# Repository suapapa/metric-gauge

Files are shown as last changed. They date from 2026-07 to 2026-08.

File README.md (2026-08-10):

# Metric Gauge

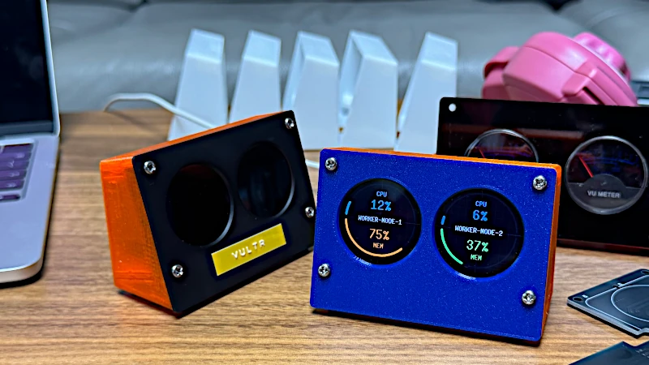
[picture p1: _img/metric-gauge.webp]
metric-gauge


ESP32-C3 Super Mini + dual **GC9A01** round LCDs (240×240). Each display shows a circle gauge with **CPU** and **MEM** from a Prometheus metrics URL (node-exporter or mon64 export).

Metric source sibling project: [mon64](https://github.com/suapapa/mon64).

## Hardware

| Part | Notes |
|---|---|
| MCU | ESP32-C3 Super Mini |
| Displays | 2× GC9A01 1.28″ round TFT, **4-wire SPI** |

> GC9A01 modules often label MOSI/SCK as **SDA/SCL**. That is still SPI, not I²C.

### Pin map

| Signal | GPIO | Notes |
|---|---|---|
| SCK (SCL) | **6** | Shared SPI clock |
| MOSI (SDA) | **7** | Shared SPI data |
| RST | **0** | Shared reset |
| BL | **5** | Shared backlight (driven high) |
| CS1 | **10** | Gauge 1 chip select |
| DC1 | **1** | Gauge 1 data/command |
| CS2 | **3** | Gauge 2 chip select |
| DC2 | **4** | Gauge 2 data/command |

Avoid strapping pins **2 / 8 / 9** for CS/DC if possible. UART0 (**20/21**) is left free for USB serial.

Power both modules from **3V3** (logic is 3.3 V). Do not feed 5 V into GPIO.

## Build / flash

Requires a Rust nightly toolchain with `riscv32imc-unknown-none-elf` (see `rust-toolchain.toml`) and [`espflash`](https://github.com/esp-rs/espflash).

Compile-time env vars (required for a useful image):

| Env | Alias | Purpose |
|-----|---|---|
| `SSID` | — | Wi-Fi SSID |
| `PASS` | `PASSWORD` | Wi-Fi password |
| `GAUGE1_PROM_METRIC` | — | Prometheus URL for display 1 |
| `GAUGE2_PROM_METRIC` | — | Prometheus URL for display 2 |
| `GAUGE1_ROTATION` | — | Rotation for display 1 (`0`, `90`, `180`, `270` or `RotateX`) |
| `GAUGE2_ROTATION` | — | Rotation for display 2 (`0`, `90`, `180`, `270` or `RotateX`) |
| `GAUGE1_NAME` | — | Name of the gauge 1 (drawn on the display 1) |
| `GAUGE2_NAME` | — | Name of the gauge 2 (drawn on the display 2) |

Copy `.env.sample` to `.env` and edit it to fit your configuration:

```bash
cp .env.sample .env
# Edit the .env file to set your SSID, PASS, and metrics endpoints
```

Run and flash directly (uses the runner in `.cargo/config.toml` to call `espflash flash --monitor --chip esp32c3`):

```bash
cargo run --release
```

Build only:

```bash
cargo build --release
```

Flash an already-built binary:

```bash
espflash flash --monitor --chip esp32c3 \
  target/riscv32imc-unknown-none-elf/release/metric-gauge
```

### Metrics notes

- Scrapes every **10 s** over HTTPS (TLS cert verification disabled). Each gauge keeps its TCP/TLS connection alive between scrapes when the server allows HTTP/1.1 keep-alive.
- Supports **node-exporter** (`node_cpu_seconds_total`, `node_memory_MemTotal_bytes` / `MemAvailable_bytes`) and **mon64** gauges (`mon64_node_cpu_percent`, `mon64_node_mem_used_percent`, …).
- Node-exporter CPU needs two samples: first scrape shows `n/a` for CPU, then deltas work.
- Hostname label on the gauge is configured via `GAUGE1_NAME` and `GAUGE2_NAME` (e.g. `node1`, `node2`).
- Displays share one static 240×240 RGB565 framebuffer (~112 KiB); both LCDs are painted sequentially over the shared SPI bus.

## License

This project is licensed under the MIT License - see the [LICENSE](LICENSE) file for details.

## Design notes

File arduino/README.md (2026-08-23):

# Metric Gauge (Arduino)

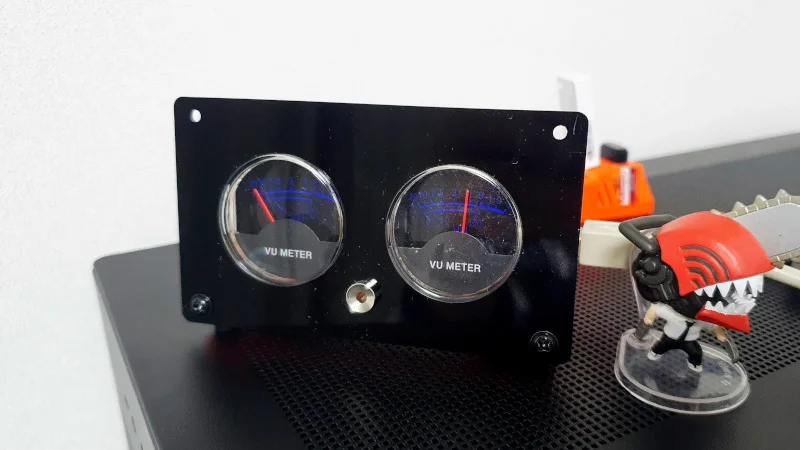
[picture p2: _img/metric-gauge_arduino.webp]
metric_gauge


Analog dual-gauge display driven by an Arduino over USB serial. A small Go daemon on the host reads CPU and memory usage (locally via gopsutil, or from a node-exporter `/metrics` URL) and sends PWM targets to the board.

For the ESP32-C3 + GC9A01 digital gauge firmware, see the [project README](../README.md).

## Hardware

| Part | Notes |
|---|---|
| MCU | Arduino (or compatible board with `analogWrite`) |
| Gauges | 2× analog meter movements on PWM outputs |
| Host link | USB serial, **9600** baud |

### Pin map (`dual_gauge.ino`)

| Signal | Pin | Notes |
|---|-----|---|
| Gauge 1 (A1) | **11** | PWM output |
| Gauge 2 (A2) | **10** | PWM output |
| Status LED | `LED_BUILTIN` | Blinks while a serial command is processed |

Values are mapped from 0–100 (percent) to 0–255 (PWM). The sketch ramps the needle smoothly (~10 ms per step) instead of jumping instantly.

## Flash the Arduino sketch

1. Open [`dual_gauge.ino`](dual_gauge.ino) in the Arduino IDE.
2. Select your board and serial port.
3. Upload.

On boot the sketch prints:

```
Type command: A=[0-100],[0-100] or A[1|2]=[0-100]
```

## Serial protocol

Commands are newline-terminated (`\n` or `\r\n`).

| Command | Effect |
|---|---|
| `A=<left>,<right>` | Set both gauges (each 0–100) |
| `A1=<value>` | Set gauge 1 only |
| `A2=<value>` | Set gauge 2 only |

Examples:

```
A=42,67
A1=80
A2=15
```

## Host daemon (`server/`)

The Go program opens the serial port and periodically writes `A=<cpu>,<mem>`.

### Run locally

```bash
cd server
go run . -s /dev/ttyUSB0 -i 15s
```

| Flag | Default | Purpose |
|---|---|---|
| `-s` | `/dev/ttyUSB0` | Serial device path |
| `-i` | `15s` | Scrape / update interval |
| `-nodeexporter` | *(empty)* | node-exporter `/metrics` URL; when set, local gopsutil is disabled |

**Local mode** (no `-nodeexporter`): reads CPU and memory from the machine running the daemon via [gopsutil](https://github.com/shirou/gopsutil).

**node-exporter mode**: fetches Prometheus text from the given URL. CPU usage is computed from `node_cpu_seconds_total` deltas (first sample may report 0% CPU until a second scrape). Memory is derived from `node_memory_MemTotal_bytes` and `node_memory_MemAvailable_bytes`.

On shutdown (SIGINT / SIGTERM) the daemon sends `A=0,0` to zero both gauges.

### Build & run with Docker

Build from the `server/` directory:

```bash
cd server
docker build -t dev/metric_gauge:latest .
```

Run with the serial device attached:

```bash
docker run \
  -d --restart unless-stopped \
  --device /dev/ttyUSB0 \
  --name metric_gauge \
  dev/metric_gauge:latest
```

Pass extra flags after the image name, for example:

```bash
docker run \
  -d --restart unless-stopped \
  --device /dev/ttyUSB0 \
  --name metric_gauge \
  dev/metric_gauge:latest \
  -i 10s -nodeexporter http://host.docker.internal:9100/metrics
```

Adjust `/dev/ttyUSB0` to match your adapter (`/dev/ttyACM0`, etc.).

## License

This project is licensed under the MIT License — see [LICENSE](../LICENSE).

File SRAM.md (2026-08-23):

빌드된 바이너리에서 SRAM 사용량을 집계해 표로 정리합니다.

현재 release 바이너리 기준입니다. (ESP32-C3 온칩 **SRAM 400 KiB**, 그중 ~16 KiB는 ICACHE)

## 칩 / 링커 창

| 구역 | 크기 |
|---|---|
| 온칩 SRAM 전체 | **400 KiB** |
| ICACHE | ~16 KiB |
| DRAM + dram2 창 | **~378 KiB** |
| IRAM용으로 예약(`.rwdata_dummy`와 동일 물리) | **~39 KiB** |

## 섹션별 (데이터 버스 DRAM)

| 섹션 | 크기 | 역할 |
|---|---|---|
| `.data` + `.data.wifi` | **~7.9 KiB** | 초기화 데이터 |
| `.bss` | **~197.6 KiB** | FB, HTTP 슬롯, Wi‑Fi BSS 등 |
| `.stack` | **~68.3 KiB** | 링커 스택 예약 |
| `.dram2_uninit` | **56.0 KiB** | `esp_alloc` heap (Wi‑Fi 동적 버퍼) |
| **합(더미 제외)** | **~330 KiB** | |

## `.bss` 안 큰 항목

| 항목 | 크기 |
|---|---|
| `FrameBuffer` 240×240 RGB565 | **~112.5 KiB** |
| HTTP keep-alive `SLOTS` ×2 (TCP+TLS 버퍼) | **~59.1 KiB** |
| embassy main task `POOL` | **~9.4 KiB** |
| Wi‑Fi `g_cnxMgr` 등 | **~수 KiB** |
| `StackResources` StaticCell | **~3.1 KiB** |

## IRAM (명령 버스, 같은 SRAM)

| 항목 | 크기 |
|---|---|
| `.rwtext.wifi` | **~33.0 KiB** |
| `.rwtext` + `.trap` | **~6.2 KiB** |
| **IRAM 합** | **~39 KiB** |

## 한눈에

| | |
|--|--|
| 앱이 크게 쓰는 곳 | FB **112** + HTTP×2 **59** + heap **56** + stack 예약 **68** |
| 여유 | dram2 heap 뒤 **~9 KiB**, 그 외는 거의 찬 편 |

물리적으로는 IRAM(~39)과 DRAM 데이터(~330)가 **같은 400 KiB SRAM**을 나눠 씁니다.

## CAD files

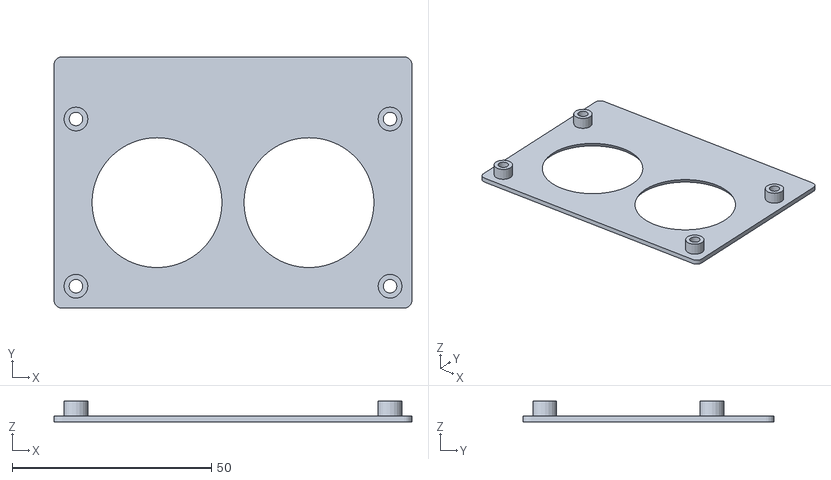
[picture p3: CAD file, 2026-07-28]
case/front.stl
89.7 x 63.0 x 5.20

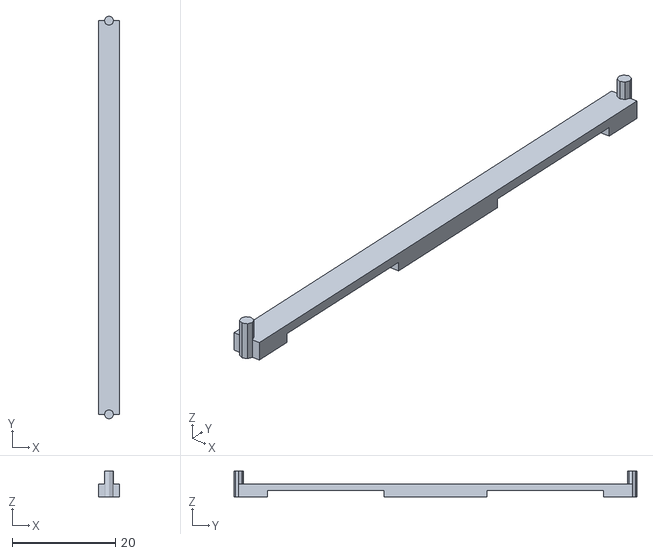
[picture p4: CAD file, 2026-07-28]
case/support.stl
4.00 x 78.0 x 5.00

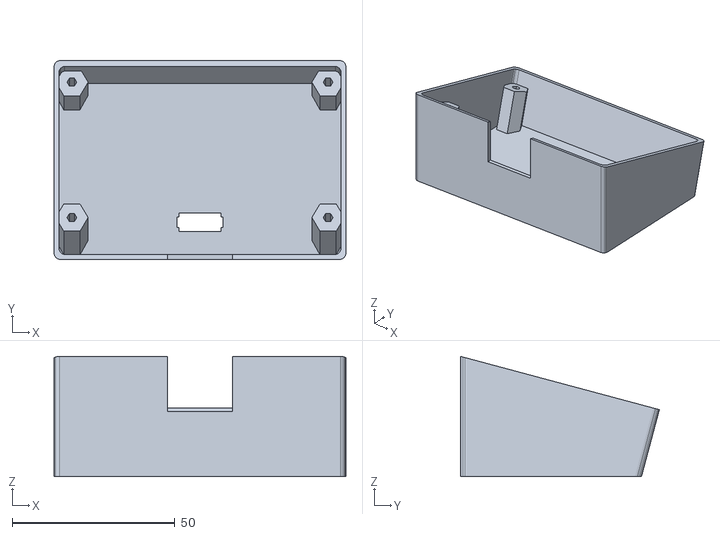
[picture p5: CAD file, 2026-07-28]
case/back.stl
89.7 x 61.1 x 36.9

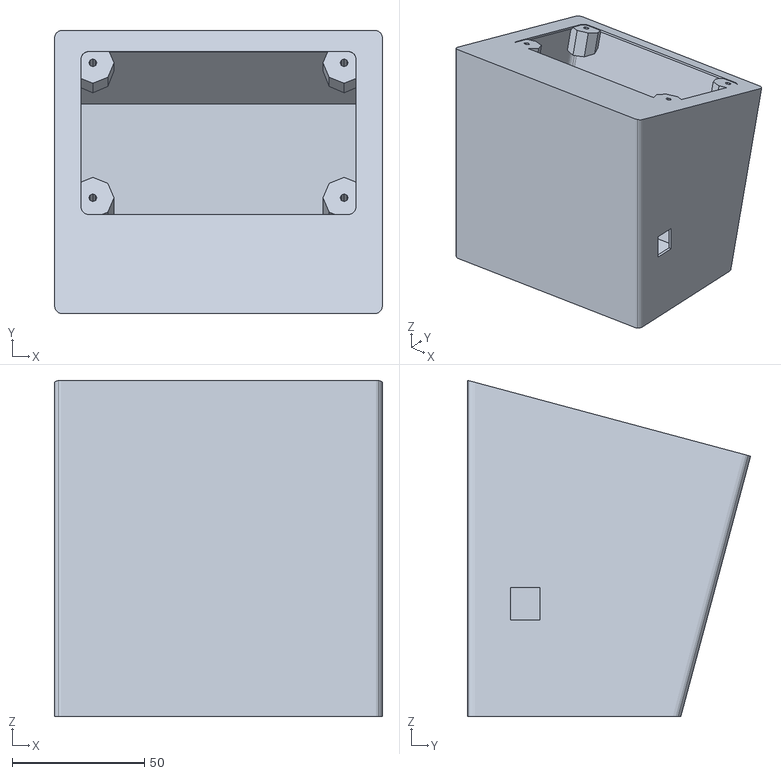
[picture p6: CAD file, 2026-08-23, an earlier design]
case/old.stl
124.0 x 107.1 x 127.2

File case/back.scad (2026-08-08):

a=15;

hw=78.74;
hh=41.91;

w=hw+4; // 100;
h=hh+4; // 60;

union() {
    difference() {
        abox(w+3, h+3);
        translate([0,0,1.5]) abox(w, h);
        
        translate([0,-15,0]) cb(14.2, 3.2);
        translate([0,-15,0]) cb(13, 5.7);
        
        // #translate([0,-30,30]) cube([20,50,20], center=true);
    }
    apillas(hw, hh);
}

module abox(w, h, r=2){
    translate([-w/2, -h/2, 0]) difference() {
        hull() {
            cylinder(50, r, r, $fn=18);
            translate([w, 0, 0]) cylinder(50, r, r, $fn=18);
            translate([0, h, -10]) rotate([-a,0,0])cylinder(70, r, r, $fn=18);
            translate([w, h, -10]) rotate([-a,0,0]) cylinder(70, r, r, $fn=18);
        }
        translate([-200,-200,-400]) cube(400);
        translate([-200,-200,90]) rotate([-a,0,0]) cube(400);
    }
}

module apillas(w, h, r=5){
    translate([-w/2, -h/2, 0]) difference() {
        union() {
            rotate([-a,0,0]) cylinder(50, r, r, $fn=6);
            translate([w, 0, 0]) rotate([-a,0,0]) cylinder(50, r, r, $fn=6);
            translate([0, h, -10]) rotate([-a,0,0])cylinder(70, r, r, $fn=6);
            translate([w, h, -10]) rotate([-a,0,0]) cylinder(70, r, r, $fn=6);
        }
        hr=1.5;
        rotate([-a, 0, 0]) translate([0,0,1]) cylinder(50, hr, hr, $fn=6);
        translate([w, 0, 0]) rotate([-a,0,0]) translate([0,0,1]) cylinder(50, hr, hr, $fn=6);
        translate([0, h, -10]) rotate([-a,0,0]) translate([0,0,1]) cylinder(70, hr, hr, $fn=6);
        translate([w, h, -10]) rotate([-a,0,0]) translate([0,0,1]) cylinder(70, hr, hr, $fn=6);
        translate([-200,-200,-400]) cube(400);
        #translate([-200,-200,90-6.8-2.5]) rotate([-a,0,0]) cube(400);
    }
}

module cb(w, h) {
    translate([-w/2,-h/2,-20]) cube([w, h, 100]);
}

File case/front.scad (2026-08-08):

z=1.5;
pw=78.74;
ph=41.91;
plw=89.74;
plh=63;
g=(plw-pw)/2; // 5.5

difference() {
    union() {
        translate([g,g,0]) pillas(pw,ph,5.2+2.2+0.5,3);
        plate(plw,plh,2);
    }
    translate([g,g,-2]) pillas(pw,ph,10,1.7);
    translate([0,g,0]) lcdholes();
}

module pillas(w, h, z, r) {
    w=78.74;
    h=41.91;
    translate([0,0,0]) union() {
        cylinder(z,r,r,$fn=20);
        translate([w,0,0]) cylinder(z,r,r,$fn=20);
        translate([0,h,0]) cylinder(z,r,r,$fn=20);
        translate([w,h,0]) cylinder(z,r,r,$fn=20);
    }
}

module plate(w, h, r) {
    z=1.5+0.5;
    linear_extrude(z) hull() {
        translate([r,r,0]) circle(r,$fn=20);
        translate([r,h-r,0]) circle(r,$fn=20);
        translate([w-r,r,0]) circle(r,$fn=20);
        translate([w-r,h-r,0]) circle(r,$fn=20);        
    }
}

module lcdholes() {
    h=20.955;
    w=38.1;
    translate([(plw-w)/2,h,-0.4]) cylinder(3, 35/2, 32/2,$fn=120);
    translate([(plw-w)/2+w,h,-0.4]) cylinder(3, 35/2, 32/2,$fn=120);
}

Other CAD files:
case/back_2.scad
case/front_2.scad
case/old.scad
case/support.scad

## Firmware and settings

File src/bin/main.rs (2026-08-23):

#![no_std]
#![no_main]
#![deny(
    clippy::mem_forget,
    reason = "mem::forget is generally not safe to do with esp_hal types, especially those \
    holding buffers for the duration of a data transfer."
)]
#![deny(clippy::large_stack_frames)]

use core::cell::RefCell;

use embassy_executor::Spawner;
use embassy_net::{DhcpConfig, Runner, Stack, StackResources};
use embassy_time::{Delay, Duration, Timer};
use embedded_hal_bus::spi::RefCellDevice;
use metric_gauge::{
    config::{self, GAUGE1_URL, GAUGE2_URL, GAUGE1_NAME, GAUGE2_NAME, PASS, SSID},
    http::fetch_prometheus,
    metrics::CpuHistory,
    render::{FrameBuffer, render_gauge},
};
use esp_hal::{
    clock::CpuClock,
    delay::Delay as BlockingDelay,
    gpio::{Level, Output, OutputConfig},
    interrupt::software::SoftwareInterruptControl,
    rng::Rng,
    spi::{
        Mode,
        master::{Config as SpiConfig, Spi},
    },
    time::Rate,
    timer::timg::TimerGroup,
};
use esp_println::println;
use esp_radio::wifi::{Config as WifiConfig, WifiController, sta::StationConfig};
use gc9a01::{
    Gc9a01, SPIDisplayInterface, display::DisplayResolution240x240, mode::DisplayConfiguration,
};
use static_cell::{ConstStaticCell, StaticCell};

#[panic_handler]
fn panic(info: &core::panic::PanicInfo) -> ! {
    println!("PANIC: {info}");
    loop {}
}

extern crate alloc;

esp_bootloader_esp_idf::esp_app_desc!();

macro_rules! mk_static {
    ($t:ty, $val:expr) => {{
        static STATIC_CELL: StaticCell<$t> = StaticCell::new();
        #[deny(unused_attributes)]
        let x = STATIC_CELL.uninit().write(($val));
        x
    }};
}

// ESP32-C3 Super Mini + dual GC9A01 (4-wire SPI).
// Round modules often label MOSI/SCK as SDA/SCL — still SPI, not I²C.
//
// Shared: SCK=GPIO6, MOSI=GPIO7, RST=GPIO0, BL=GPIO5
// Gauge1: CS=GPIO10, DC=GPIO1
// Gauge2: CS=GPIO3,  DC=GPIO4

struct RotationInterface<DI> {
    inner: DI,
    madctl: u8,
    intercept_madctl: bool,
}

impl<DI> RotationInterface<DI> {
    const fn new(inner: DI, madctl: u8) -> Self {
        Self {
            inner,
            madctl,
            intercept_madctl: false,
        }
    }
}

impl<DI: display_interface::WriteOnlyDataCommand> display_interface::WriteOnlyDataCommand
    for RotationInterface<DI>
{
    fn send_commands(
        &mut self,
        cmd: display_interface::DataFormat<'_>,
    ) -> Result<(), display_interface::DisplayError> {
        if let display_interface::DataFormat::U8(slice) = cmd {
            if !slice.is_empty() && slice[0] == 0x36 {
                if slice.len() > 1 {
                    let mut modified = [0u8; 16];
                    let len = slice.len().min(16);
                    modified[..len].copy_from_slice(&slice[..len]);
                    modified[1] = self.madctl;
                    return self
                        .inner
                        .send_commands(display_interface::DataFormat::U8(&modified[..len]));
                } else {
                    self.intercept_madctl = true;
                }
            }
            self.inner
                .send_commands(display_interface::DataFormat::U8(slice))
        } else {
            self.inner.send_commands(cmd)
        }
    }

    fn send_data(
        &mut self,
        buf: display_interface::DataFormat<'_>,
    ) -> Result<(), display_interface::DisplayError> {
        if self.intercept_madctl {
            self.intercept_madctl = false;
            if let display_interface::DataFormat::U8(slice) = buf {
                if !slice.is_empty() {
                    let mut modified = [0u8; 16];
                    let len = slice.len().min(16);
                    modified[..len].copy_from_slice(&slice[..len]);
                    modified[0] = self.madctl;
                    return self
                        .inner
                        .send_data(display_interface::DataFormat::U8(&modified[..len]));
                }
                return self
                    .inner
                    .send_data(display_interface::DataFormat::U8(slice));
            }
        }
        self.inner.send_data(buf)
    }
}

#[allow(
    clippy::large_stack_frames,
    reason = "display state and scrape loop live in main"
)]
#[esp_rtos::main]
async fn main(spawner: Spawner) -> ! {
    // C3 max is 160 MHz; 80 MHz cuts idle heat a lot (TLS scrape still OK).
    let config = esp_hal::Config::default().with_cpu_clock(CpuClock::_80MHz);
    let peripherals = esp_hal::init(config);

    esp_alloc::heap_allocator!(#[esp_hal::ram(reclaimed)] size: 56 * 1024);

    let timg0 = TimerGroup::new(peripherals.TIMG0);
    let sw_interrupt = SoftwareInterruptControl::new(peripherals.SW_INTERRUPT);
    esp_rtos::start(timg0.timer0, sw_interrupt.software_interrupt0);

    esp_println::logger::init_logger_from_env();
    println!("metric-gauge boot");
    println!("SSID len={} PASS len={}", SSID.len(), PASS.len());
    println!("gauge1={GAUGE1_URL}");
    println!("gauge2={GAUGE2_URL}");
    println!("gauge1 rotation={:?}", config::GAUGE1_ROTATION);
    println!("gauge2 rotation={:?}", config::GAUGE2_ROTATION);

    // --- Displays ---
    let mut rst = Output::new(peripherals.GPIO0, Level::High, OutputConfig::default());
    let mut bl = Output::new(peripherals.GPIO5, Level::High, OutputConfig::default());
    let _ = bl.set_high();

    let spi = Spi::new(
        peripherals.SPI2,
        SpiConfig::default()
            .with_frequency(Rate::from_mhz(64)) //40
            .with_mode(Mode::_0),
    )
    .expect("SPI2 init")
    .with_sck(peripherals.GPIO6)
    .with_mosi(peripherals.GPIO7);

    let spi_bus = RefCell::new(spi);
    let spi_dev1 = RefCellDevice::new(
        &spi_bus,
        Output::new(peripherals.GPIO10, Level::High, OutputConfig::default()),
        Delay,
    );
    let spi_dev2 = RefCellDevice::new(
        &spi_bus,
        Output::new(peripherals.GPIO3, Level::High, OutputConfig::default()),
        Delay,
    );

    let iface1 = RotationInterface::new(
        SPIDisplayInterface::new(
            spi_dev1,
            Output::new(peripherals.GPIO1, Level::Low, OutputConfig::default()),
        ),
        config::GAUGE1_MADCTL,
    );
    let iface2 = RotationInterface::new(
        SPIDisplayInterface::new(
            spi_dev2,
            Output::new(peripherals.GPIO4, Level::Low, OutputConfig::default()),
        ),
        config::GAUGE2_MADCTL,
    );

    let mut display1 = Gc9a01::new(iface1, DisplayResolution240x240, config::GAUGE1_ROTATION);
    let mut display2 = Gc9a01::new(iface2, DisplayResolution240x240, config::GAUGE2_ROTATION);

    let mut blocking_delay = BlockingDelay::new();
    let _ = display1.reset(&mut rst, &mut blocking_delay);
    let _ = display1.init(&mut blocking_delay);
    let _ = display2.init(&mut blocking_delay);
    println!("displays ready");

    // ConstStaticCell keeps the 112 KiB FB in .bss — never materialize it on stack.
    static FB: ConstStaticCell<FrameBuffer> = ConstStaticCell::new(FrameBuffer::new());
    let fb = FB.take();
    paint_gauge(
        &mut display1,
        fb,
        Some(0.0),
        Some(0.0),
        "boot",
        true,
        true,
    );
    paint_gauge(
        &mut display2,
        fb,
        Some(0.0),
        Some(0.0),
        "boot",
        true,
        true,
    );

    // --- Wi-Fi ---
    let rng = Rng::new();
    let (wifi_controller, interfaces) =
        esp_radio::wifi::new(peripherals.WIFI, Default::default()).expect("Wi-Fi init");

    let wifi_interface = interfaces.station;
    let mac = wifi_interface.mac_address();
    println!(
        "STA MAC {:02X}:{:02X}:{:02X}:{:02X}:{:02X}:{:02X}",
        mac[0], mac[1], mac[2], mac[3], mac[4], mac[5]
    );
    let net_seed = u64::from(rng.random()) | (u64::from(rng.random()) << 32);
    let tls_seed = u64::from(rng.random()) | (u64::from(rng.random()) << 32);

    let (stack, runner) = embassy_net::new(
        wifi_interface,
        embassy_net::Config::dhcpv4(DhcpConfig::default()),
        mk_static!(StackResources<4>, StackResources::<4>::new()),
        net_seed,
    );

    spawner.spawn(connection(wifi_controller).unwrap());
    spawner.spawn(net_task(runner).unwrap());

    wait_for_connection(stack).await;
    println!("network up");

    let host1 = GAUGE1_NAME;
    let host2 = GAUGE2_NAME;
    let mut hist1 = CpuHistory::default();
    let mut hist2 = CpuHistory::default();

    let mut tls_seed = tls_seed;
    let mut heartbeat = false;
    loop {
        heartbeat = !heartbeat;
        let stats1 = fetch_prometheus(stack, 0, tls_seed, GAUGE1_URL, &mut hist1).await;
        tls_seed = tls_seed.wrapping_add(0x9E37_79B9_7F4A_7C15);
        let stats2 = fetch_prometheus(stack, 1, tls_seed, GAUGE2_URL, &mut hist2).await;
        tls_seed = tls_seed.wrapping_add(0x9E37_79B9_7F4A_7C15);

        paint_gauge(
            &mut display1,
            fb,
            stats1.cpu_percent,
            stats1.mem_percent,
            host1,
            stats1.reachable,
            heartbeat,
        );
        paint_gauge(
            &mut display2,
            fb,
            stats2.cpu_percent,
            stats2.mem_percent,
            host2,
            stats2.reachable,
            heartbeat,
        );

        println!(
            "g1 cpu={:?} mem={:?} | g2 cpu={:?} mem={:?}",
            stats1.cpu_percent, stats1.mem_percent, stats2.cpu_percent, stats2.mem_percent
        );

        Timer::after(Duration::from_secs(10)).await;
    }
}

fn paint_gauge<I>(
    display: &mut Gc9a01<I, DisplayResolution240x240, gc9a01::mode::BasicMode>,
    fb: &mut FrameBuffer,
    cpu: Option<f32>,
    mem: Option<f32>,
    hostname: &str,
    reachable: bool,
    alive: bool,
) where
    I: display_interface::WriteOnlyDataCommand,
{
    render_gauge(fb, cpu, mem, hostname, reachable, alive);
    // MemoryWrite (0x2C) must precede pixels; draw_buffer skips it.
    let mut colors = fb.pixels.iter().copied();
    let _ = display.set_pixels((0, 0), (239, 239), &mut colors);
}

async fn wait_for_connection(stack: Stack<'_>) {
    println!("waiting for link");
    loop {
        if stack.is_link_up() {
            break;
        }
        Timer::after(Duration::from_millis(500)).await;
    }
    println!("waiting for DHCP");
    loop {
        if let Some(config) = stack.config_v4() {
            println!("IP {}", config.address);
            break;
        }
        Timer::after(Duration::from_millis(500)).await;
    }
}

#[allow(clippy::large_stack_frames)]
#[embassy_executor::task]
async fn connection(mut controller: WifiController<'static>) {
    println!("wifi connection task");
    // ESP32-C3 Super Mini: default ~20 dBm often yields AuthenticationExpired
    // during WPA (poor onboard antenna match). 8.5 dBm is the usual fix.
    // Unit is 0.25 dBm → 34 ≈ 8.5 dBm. Must be set after start, before connect.
    const TX_POWER: i8 = 34;
    loop {
        if controller.is_connected() {
            let _ = controller.wait_for_disconnect_async().await;
            println!("wifi disconnected");
            // Full radio while reconnecting.
            let _ = controller.set_power_saving(esp_radio::wifi::PowerSaveMode::None);
            Timer::after(Duration::from_secs(3)).await;
        }

        let station_config = WifiConfig::Station(
            StationConfig::default()
                .with_ssid(SSID)
                .with_password(PASS.into()),
        );
        if let Err(e) = controller.set_config(&station_config) {
            println!("wifi set_config: {e:?}");
            Timer::after(Duration::from_secs(3)).await;
            continue;
        }

        // set_config starts the radio; TX must be lowered before auth.
        let _ = controller.set_power_saving(esp_radio::wifi::PowerSaveMode::None);
        if let Err(e) = controller.set_max_tx_power(TX_POWER) {
            println!("wifi set_max_tx_power: {e:?}");
        } else {
            println!("wifi tx power {TX_POWER}/0.25dBm (~8.5dBm)");
        }

        println!("wifi connecting…");
        match controller.connect_async().await {
            Ok(_) => {
                println!("wifi connected");
                // Keep modem awake: Minimum sleep regularly stalls TCP/TLS
                // handshakes to remote HTTPS (hangs after "fetch host -> ip").
                let _ = controller.set_power_saving(esp_radio::wifi::PowerSaveMode::None);
            }
            Err(e) => {
                println!("wifi connect failed: {e:?}");
                Timer::after(Duration::from_secs(5)).await;
            }
        }
    }
}

#[embassy_executor::task]
async fn net_task(mut runner: Runner<'static, esp_radio::wifi::Interface<'static>>) -> ! {
    runner.run().await
}

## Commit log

2026-07-23 Initialize project structure for ESP32-C3
    Add configuration files, core dependencies, build scripts, and a
    minimal application skeleton for the esp-dual-gauge project.
2026-07-23 Add firmware core implementation
    - Add `AGENTS.md` and `README.md`
    - Implement main loop with dual-display SPI rendering
    - Implement streaming HTTP/TLS client and Prometheus parser
    - Add `build.rs` for compile-time environment configuration
2026-07-23 Improve HTTPS robustness and TLS configuration
    - Enable RSA signatures and ALPN in TLS config
    - Use HTTP/1.0 to avoid chunked body encoding
    - Implement socket abort/flush and DNS caching
    - Add connection retry logic for DNS queries
    [main.rs]
2026-07-23 Reduce power consumption and thermal output
    Set CPU clock to 80 MHz and enable Wi-Fi power saving after connection,
    with a minor reduction in TX power to improve thermal efficiency on the
    ESP32-C3 Super Mini.
2026-07-24 Reduce Wi-Fi transmit power to 8.5 dBm
    Adjusts TX power during the connection process to improve stability on
    the
    ESP32-C3 Super Mini. Also adds credential length logging for debugging.
    [main.rs]
2026-07-24 Fix band rendering and implement scaled text drawing
    Use `set_pixels` instead of `draw_buffer` to ensure proper
    MemoryWrite command execution.
    Introduce `ScaledDrawTarget` to allow rendering text with a 2x scale
    factor. This improves the visibility of the 'big' text style by
    effectively scaling the font geometry.
    [main.rs]
2026-07-24 Increase SPI frequency and add connection timeouts
    Increase SPI frequency to 64MHz and set Wi-Fi power save to None
    to prevent TCP/TLS handshake hangs.
    Add `embassy_time::with_timeout` to TCP, TLS, and HTTP operations
    to prevent hung connections during scrapes.
    Improve error logging for TCP connection and TLS handshake stages.
    [main.rs]
2026-07-26 Rename project from esp-dual-gauge to metric-gauge
    Rename the project package name, binary name, and crate name
    to metric-gauge across Cargo.toml, Cargo.lock, and source files.
    Also update the project name in README.md, AGENTS.md, and the boot
    message. Finally, add KiCad file patterns to .gitignore.
2026-07-26 add sch and pcb in KiCad
    [metric-gauge-B_Cu.gbr, metric-gauge-B_Mask.gbr, metric-gauge-B_Paste.gbr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]
2026-07-26 add case OpenScad and STL files
    [back.scad, back.stl, front.scad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]
2026-07-26 Fix typos and add GAUGE_NAME configuration
    Corrected the "GUAGE" typo to "GAUGE" across the project files and
    documentation. Added support for GAUGE1_NAME and GAUGE2_NAME to allow
    explicitly setting the hostname label displayed on the gauge, rather
    than deriving it from the URL.
    [main.rs]
2026-07-28 Update case geometry and dimensions
    [back.scad, back.stl, front.scad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]
2026-08-08 Update case geometry for improved component fit
    [back.scad, front.scad]
2026-08-09 Replace band-based renderer with full framebuffer
    Switch to a single full-framebuffer renderer to simplify rendering
    logic.
    This change uses a shared static 240x240 frame buffer for both displays,
    which are painted sequentially.
    [main.rs]
2026-08-10 Implement persistent HTTP/1.1 connections
    Add a connection pooling mechanism with two dedicated slots to keep
    TCP/TLS sessions alive across scrape cycles. This avoids repeated
    handshakes for servers supporting HTTP/1.1 keep-alive.
    [main.rs]
2026-08-23 Update hardware PCB layout and firmware imports
    - Relocate mounting holes and update board footprint U2
    - Regenerate gerber files
    - Import ConstStaticCell in main and remove unused MaybeUninit in http
    module
    [metric-gauge-B_Cu.gbr, metric-gauge-B_Mask.gbr, metric-gauge-B_Paste.gbr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]
2026-08-23 Add OpenSCAD models for dual-gauge enclosure
    [back_2.scad, front_2.scad, old.scad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]
2026-08-23 Add Arduino gauge implementation and Go server
    - Add `arduino/dual_gauge.ino` for serial-controlled analog gauge output
    - Add `arduino/server/` with Go metrics scraper (node-exporter or host)
    to drive Arduino via serial
2026-08-23 Add CI workflow for Arduino server Docker image
    Introduce a GitHub Actions workflow to build and push multi-arch Docker
    images for the Arduino server component to GHCR, along with supporting
    configuration.
2026-08-23 Add Arduino-based gauge implementation
    Add documentation and support for an analog Arduino-based gauge variant
    with an associated Go host daemon for serial communication.
